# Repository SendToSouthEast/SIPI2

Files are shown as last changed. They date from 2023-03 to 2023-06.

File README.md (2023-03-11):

# SIPI2

一个基于ESP32(IDF)和LVGL实现的多功能单词机

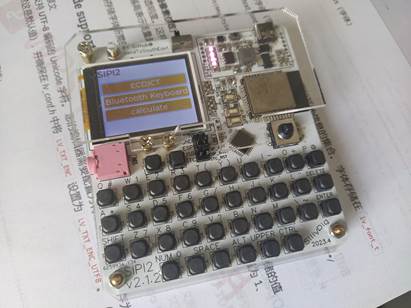
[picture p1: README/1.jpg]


<u>注：以上图片为旧版硬件SIPI2.0</u>

160x128 LCD  SPI屏幕，SPI/SDMMC内存卡存储单词内容，30余个按键全键输入，9x9.5迷你大小，硬件软件全部开源。

作者比较忙，**欢迎各位提交PR，有问题提issue**。git上的issue硬件软件问题都能问，硬件在这里提供json（JLCEDA PCB文件）和gerber。另在立创广场开源硬件项目。

若你只是想复刻这个项目，你可以到release获取所有gerber和二进制文件。

2.0问题已经全部修复，2.1版本还未验证，请知悉！！！

## 项目核心

本项目采用MIT开源，欢迎各位积极贡献代码！！！！

欢迎各位积极贡献代码！！！！

欢迎各位积极贡献代码！！！！

欢迎各位积极贡献代码！！！！

欢迎各位积极贡献代码！！！！

## 功能说明

1.查询单词

2.蓝牙键盘，可以连接手机电脑（进行中）

可开发功能

1.基于LVGL的俄罗斯方块等游戏

2.基于ESP ADF pwm或ADC的音乐播放器

3.基于LVGL的文件浏览器，电子相册

……

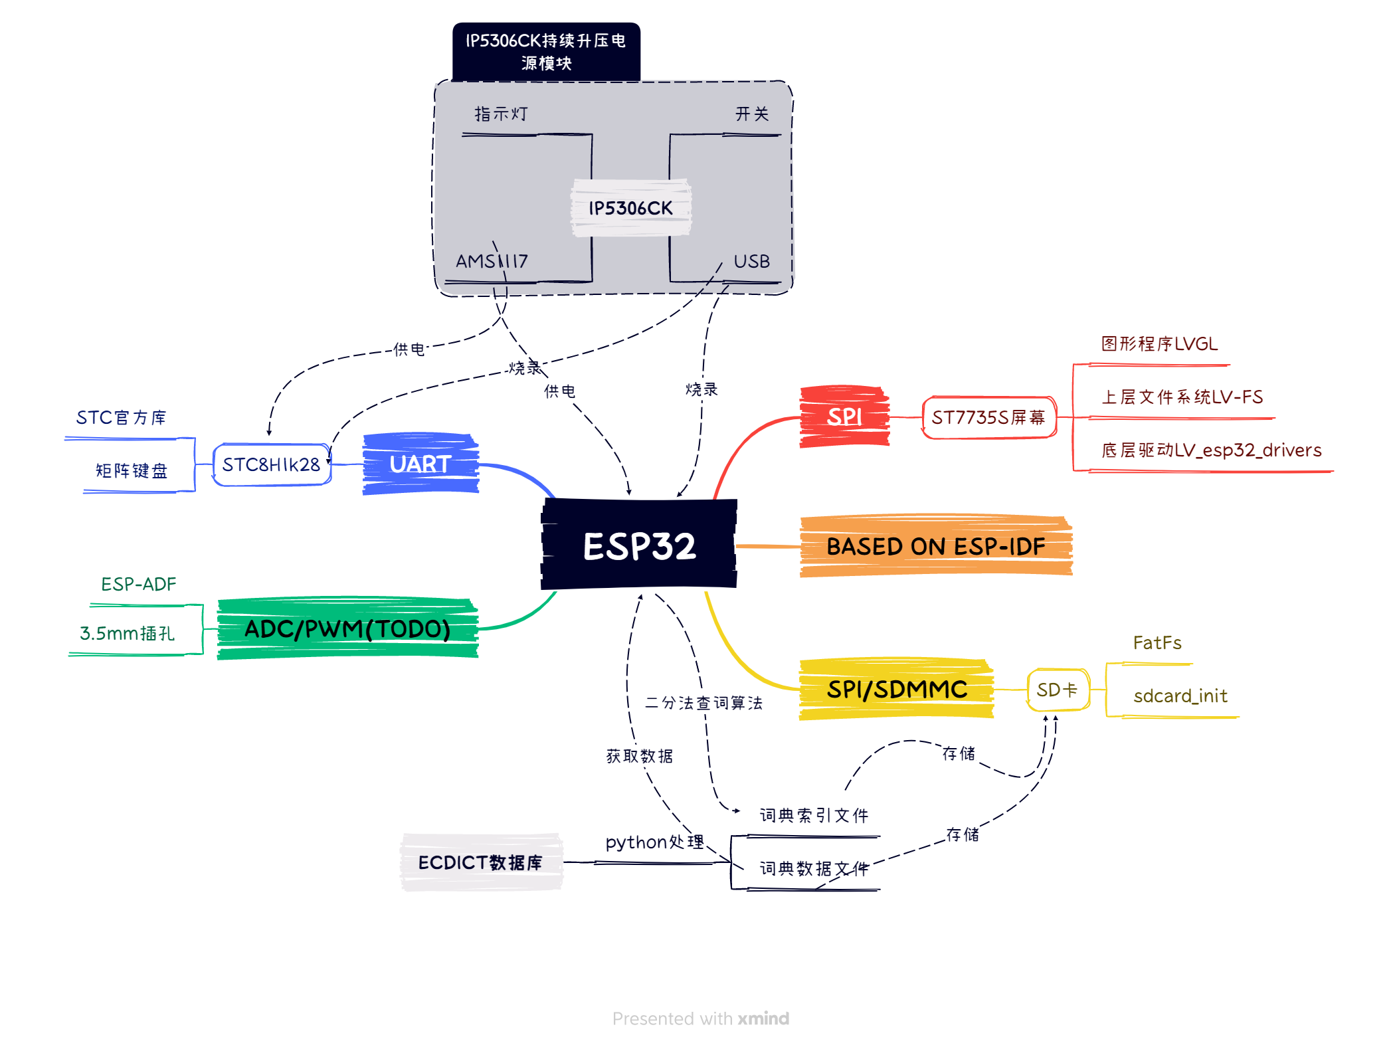
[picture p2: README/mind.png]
mind


## 使用教程

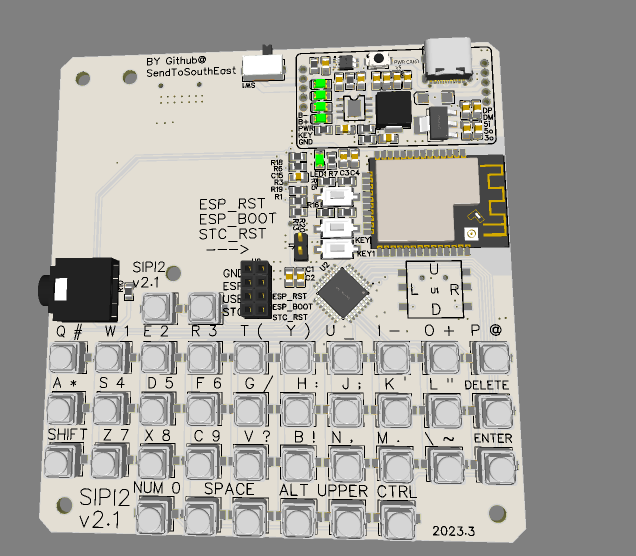
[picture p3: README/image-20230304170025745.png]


以2.1硬件为例。

### 一.烧录

板子上有ESP32的复位按键，BOOT按键和STC8的复位按键。

需要分别给ESP32和STC单片机烧录程序。

若你只是想复刻这个项目，你可以到release获取所有gerber和二进制文件。

[Releases · SendToSouthEast/SIPI2 (github.com)](https://github.com/SendToSouthEast/SIPI2/releases)

#### 1.特制烧录器

本板子不集成串口转换芯片，但是你可以使用某些（自制）非规范的USB线，即DP DM分别是电脑TXD RXD的非规范的USB烧录器连接充电口进行烧录。只需将烧录插座的2.3行(ESP,USB)竖直连起来，就像这样 （A和B代表不同的短接帽）就可以对ESP32进行烧录。

```
OO
AB
AB
OO
```

同理，短接三四行就能对STC烧录。

```
OO
OO
AB
AB
```

#### 2.普通烧录器

这四个位置的定义如下

| GND | GND |
| --- | --- |
| ESP_TXD | ESP_RXD |
| USBDM | USBDP |
| STC_TXD | STC_RXD |

#### 3.注意事项

烧录教程不再写了，网上一查便是，说下注意事项

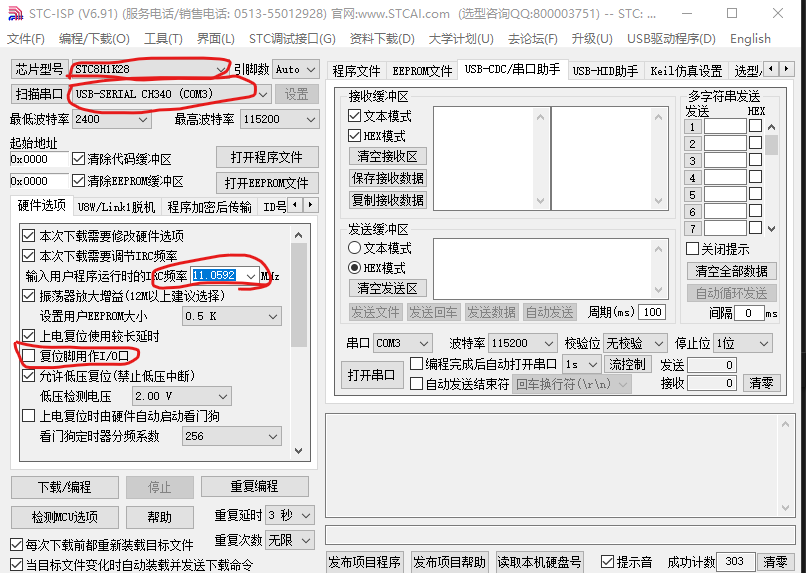
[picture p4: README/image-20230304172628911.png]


图为你烧录STC单片机的注意事项。

当你第一次烧录STC单片机时，复位脚是IO状态，你需要先点击烧录然后再给单片机供电。（具体请查）

当你关闭了复位脚用做IO口，在你**下一次烧录**时，不需要断电，先点击烧录再按下复位即可。

建议每次烧录都关闭复位脚用做IO口。注意，它默认是打开的，而且不会保存状态。

### 二.使用

打开电源后点击充电芯片的按键，开始供电。

键盘上面的左边的两个按键 是确定键，右边是返回键。

在Dict界面点击确定查词，点击返回进入蓝牙键盘模式。

在Word界面都会返回Dict界面。

目前五向按键尚未投入使用。

按下ALT后进入数字、符号输入模式

按下UPPER进入大写输入模式，再次按下即可取消。

目前因为对HID协议的通信不熟悉，导致符号输入有点问题，（HID有很多两个按键共用一个HID码）望大佬赐教。（如何同时按下shift和按键？）

蓝牙模式下可用手机连接，按照提示配置输入后就可以使用了。

讯飞输入法效果如图

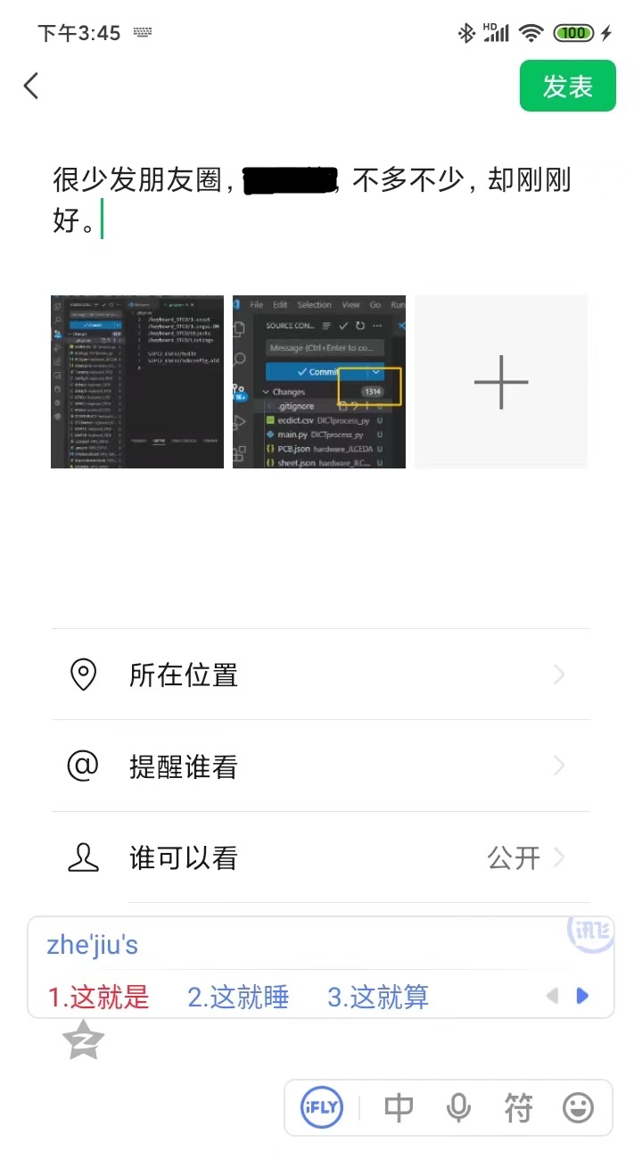
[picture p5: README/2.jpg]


## 硬件说明

**2.0问题已经全部修复，2.1.1版本还未验证，请知悉！！！**

充电部分电路参考[IP5306CK单片机电源板 - 嘉立创EDA开源硬件平台 (oshwhub.com)](https://oshwhub.com/yxynb/IP5306CKPOWERBOARD)

充电模块提供3.3V电源。

STC8单片机扫描键盘并通过串口2发送给ESP32。

### 重要物料BOM

并未有任何推广，你如果能在淘宝或者哪里买到更便宜的当然更好

| 元件 | 说明 | 示例链接 |
| --- | --- | --- |
| XB7608AJ | 锂电池保护芯片 | https://item.szlcsc.com/2775921.html |
| IP5306CK | 充电芯片（持续升压） | [原装正品 IP5306_CK ESOP-8 2.1A充电2.4A放电 移动电源SOC芯片-淘宝网 (taobao.com)](https://item.taobao.com/item.htm?spm=a1z10.3-c-s.w4002-24706531953.12.68fe6a4bBAzjuy&id=663023987923) |
| STC8H1K28-LQFP32 | 键盘扫描芯片 | [STC8H1K28-36I-LQFP32 全新原装 STC8H1K28-淘宝网 (taobao.com)](https://item.taobao.com/item.htm?spm=a230r.1.14.36.57ea73fbUVK0uj&id=615435436806&ns=1&abbucket=16#detail) |
| ESP32-WROOM32 | 主控 | 用兼容新产品也可 |
| 1.77寸TFT液晶显示屏14PIN焊接式ST7735S | 屏幕 | [1.77寸TFT液晶显示屏14PIN焊接SPI接口1.8寸显示屏14PIN串口SPI-淘宝网 (taobao.com)](https://item.taobao.com/item.htm?spm=a230r.1.14.13.41762419pn5ZGc&id=579752045837&ns=1&abbucket=16#detail) |
| 160G轻力度无声硅胶开关 | 建议买40个 | [TS-E013 硅胶按钮6*6*5/4.3贴片无声A6按键硅胶车载汽车SW-PB轻触-淘宝网 (taobao.com)](https://item.taobao.com/item.htm?spm=a1z10.3-c-s.w4002-18164922779.14.3d3c6edb4XQNIZ&id=22248047162) |
| 五向开关 | 目前没有用可以不装，买之前对照一下原理图 | [FT-007贴片10*10*5/7/9多功能多方向连接器五向开关 轻触复位按键-淘宝网 (taobao.com)](https://item.taobao.com/item.htm?spm=a1z0d.6639537/tb.1997196601.4.2b777484jefjoa&id=596429062451) |

### 外观尺寸

外观尺寸为90（w）x95（h），以左下角为坐标原点，五个螺丝孔的坐标分别为（单位mm）

| 5,5 | 5,90  |
| ----- | ----- |
| 85,5  | 15,90 |
| 25,49 | |

## 项目结构

仓库共有四个主文件夹（项目）

| 文件夹 | 说明 | 语言/IDE/平台 |
| --- | --- | --- |
| DICTprocess_py  | 将字典数据库处理为一个索引文件和一个数据文件的脚本 | python |
| hardware_JLCEDA | 硬件文件 | 嘉立创EDA |
| keyboard_STC8 | 键盘扫描程序，向主控串口发送数据 | Keil STC8H1K |
| SIPI2_ESP32 | 主控（ESP32）程序 | Vscode ESPIDF v4.4.2 |

其中字典处理的数据库来自[skywind3000/ECDICT](https://github.com/skywind3000/ECDICT)

keyboard_STC8的库文件为STC官方STC8库文件

```
│  .gitignore    // Git 版本控制忽略文件配置
│  LICENSE       // 代码许可证
│  README.md     // 项目说明文档
│
├─DICTprocess_py 	// Python 字典处理程序
│      ecdict.csv   // 英汉词典数据文件（来源见下）
│      main.py      // 主程序文件
│
├─hardware_JLCEDA 	// JLCEDA 硬件设计文件
│      PCB.json     // PCB 文件
│      sheet.json   // 原理图文件
│
├─keyboard_STC8    // STC8 键盘控制器程序
│  │  1.uvproj     // Keil uVision 项目文件
│  │  config.h     // 配置文件
│  │  delay.c      // 延时库稳健
│  │  delay.h      // 延时库头文件
│  │  GPIO.c       // GPIO 库文件
│  │  GPIO.h       // GPIO 库头文件
│  │  mian.c       // 主程序文件
│  │  STARTUP.A51  // Keil ASM 文件
│  │  STC8xxxx.H   // STC8 头文件
│  │  UART.C       // 串口库文件
│  │  UART.h       // 串口库头文件
│
├─README          // 项目说明文档
│      1.jpg      // 图片文件
│
└─SIPI2_ESP32     // ESP32 控制程序
				  //见下
				  
SIPI2_ESP32目录结构如下

│  .cproject
│  .project
│  CMakeLists.txt
│  dependencies.lock
│  partitions.csv			// 分区表文件
│  sdkconfig				// 记录ESP-IDF SDK配置选项的文件
│  sdkconfig.old
│
├─.vscode
│      c_cpp_properties.json
│      settings.json
│
├─components
│  ├─lvgl					// LittlevGL图形库组件
│  │
│  ├─lvgl_esp32_drivers     // LittlevGL在ESP32上的驱动组件
│  │
│  ├─lv_fs_if				// ESP和LVGL文件系统接口组件
│  │
│  └─sdcard_init			// SD卡初始化驱动程序组件(自编)
│          CMakeLists.txt
│          Kconfig			// 配置选项文件
│          sdcard_init.c	// SD卡初始化驱动程序的源代码文件
│          sdcard_init.h
│
└─main
	│  character.txt				// 存储字库字符的文本文件
	│  CMakeLists.txt
	│  config.h						// 配置选项头文件
	│  donotuse.txt
	│  init.c						// 初始化
	│  init.h
	│  Kconfig.projbuild
	│  main.c						// 主程序
	│  main.h
	│  simhei.c						// 简体中文黑体字体
	│
	├─scenes                        // 场景代码
	│  dictScene.c                  // 字典场景的源文件
	│  HIDScene.c                   // HID场景的源文件
	│  scenes.h                     // 场景代码的头文件
	│  wordScene.c                  // 单词场景的源文件
	│
	└─srcs							// 功能代码
    	├─blueHID					// 蓝牙HID功能代码
    	│      ble_hidd.c
 	   	│      ble_hidd.h
 	   	│      esp_hidd_prf_api.c
 	   	│      esp_hidd_prf_api.h
 	   	│      hidd_le_prf_int.h
  	  	│      hid_dev.c
  	  	│      hid_dev.h
	  	│      hid_device_le_prf.c
	    │
    	└─englishDict              // 英语词典代码
        englishDict.c              // 英语词典查词算法
        englishDict.h
```

其中，lvgl_esp32_drivers的st7735的屏幕驱动程序有修改，为兼容此屏幕。

sdcard_init是我写的component，引脚配置和模式选择在menuconfig中。之所以做成组件是因为lv_fs_if需要调用它来初始化文件系统。

本项目由去年写的代码第二次重构（第一次重构由arduino转到IDF，第二次模块化去耦），一些函数的实现没有动，若不规范欢迎大家指出改正！

## TODO

1.蓝牙键盘有点问题，目前因为对HID协议的通信不熟悉，导致符号输入有点问题，（HID有很多两个按键共用一个HID码）望大佬赐教。（如何同时按下shift和按键？

（SIPI2_ESP32\main\srcs\blueHID\ble_hidd.c）不能正确运行。

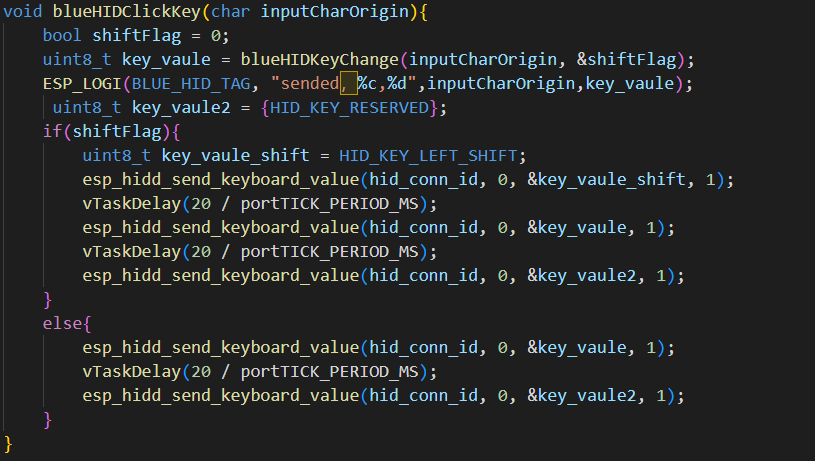
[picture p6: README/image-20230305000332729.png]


2.将五向开关利用起来

3.可能会做单词语音播放（还未开工）

4.你想做什么功能欢迎提交称为贡献者

## 开源许可

本项目采用MIT开源协议。同时也希望其它esp32项目多开源。

但是，请勿将我的项目搬运上传码云等平台。

## 鸣谢

[skywind3000/ECDICT: Free English to Chinese Dictionary Database (github.com)](https://github.com/skywind3000/ECDICT)

[lvgl/lvgl: Embedded graphics library to create beautiful UIs for any MCU, MPU and display type. It's boosted by a professional yet affordable drag and drop UI editor, called SquareLine Studio. (github.com)](https://github.com/lvgl/lvgl)

[lvgl/lvgl_esp32_drivers: Drivers for ESP32 to be used with LVGL (github.com)](https://github.com/lvgl/lvgl_esp32_drivers)

[lvgl/lv_fs_if: LVGL interfaces to various file systems (PC, FatFS) (github.com)](https://github.com/lvgl/lv_fs_if)

[espressif/esp-idf: Espressif IoT Development Framework. Official development framework for Espressif SoCs. (github.com)](https://github.com/espressif/esp-idf)

[FreeRTOS/FreeRTOS: 'Classic' FreeRTOS distribution. Started as Git clone of FreeRTOS SourceForge SVN repo. Submodules the kernel. (github.com)](https://github.com/FreeRTOS/FreeRTOS)

fatfs

感谢[ahzvenol (灵弦) (github.com)](https://github.com/ahzvenol) 的帮助

## 赞助作者

想喝一杯奶茶……可以吗

……家境贫寒……无电子词典可买……徒手搓之……





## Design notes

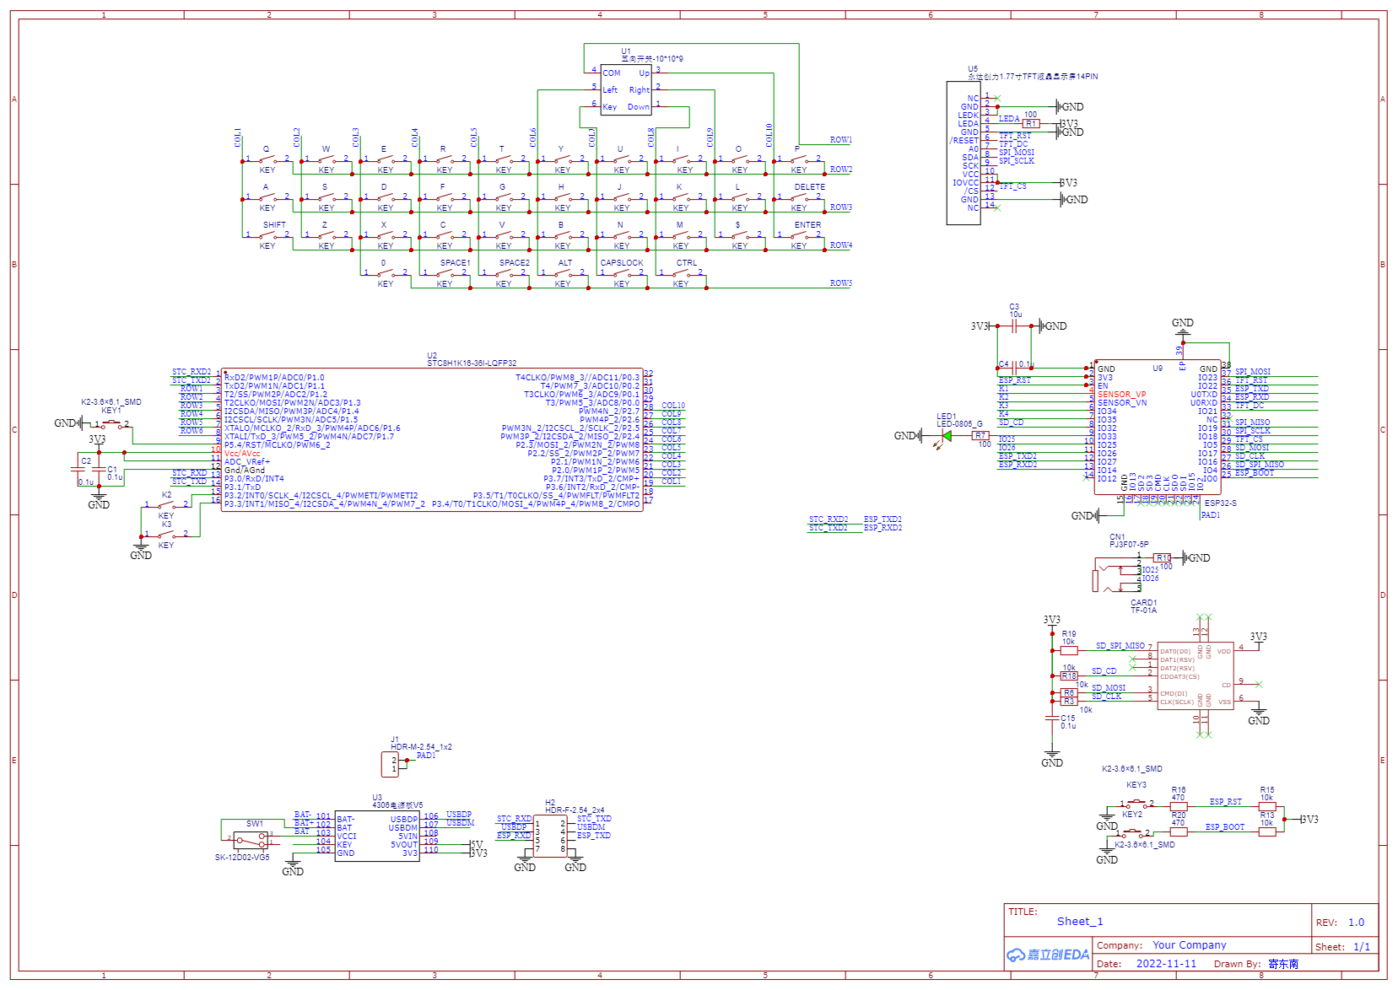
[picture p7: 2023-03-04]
hardware_JLCEDA/Schematic1.png

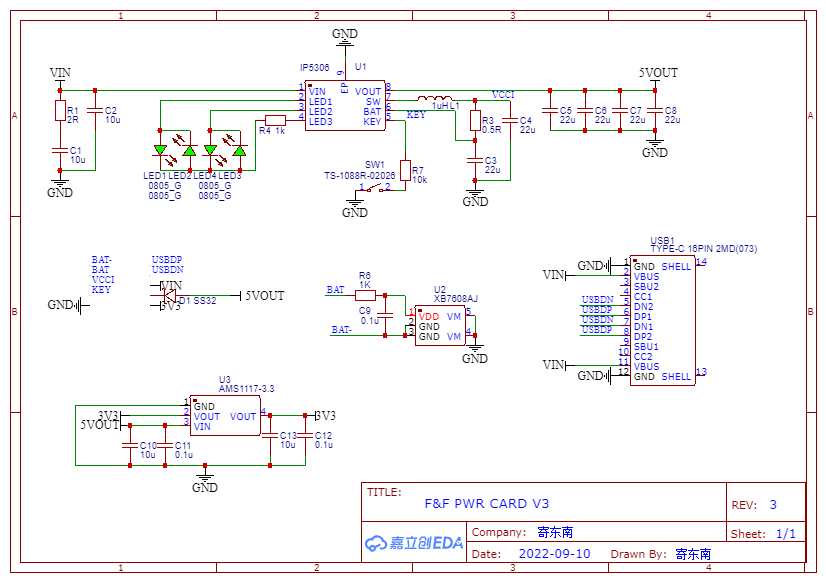
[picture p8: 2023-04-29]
hardware_JLCEDA/Schematic2.png

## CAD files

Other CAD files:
hardware_JLCEDA/亚克力双面板外壳.dwg

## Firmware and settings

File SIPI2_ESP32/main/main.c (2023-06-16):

#include "main.h"


#include "simhei.c"
#include "scenes.h"

static const char *TAG = "SIPI2_MAIN";

void keyCheakTask();

uint8_t LVKeyYBuff = 0;

bool keyYesFlag = 0;
bool keyNOFlag = 0;
bool inputFlag = 0;
char InputBuffer = 0;



// 初始化UI
void UIInit()
{
    //oald10WordSceneInit("add to");
    //oald10DictSceneInit();
    lv_obj_set_size(lv_obj_create(NULL), LV_HOR_RES, LV_VER_RES);
    mainSceneInit();
}


lv_obj_t* scr;
lv_obj_t* scr1;

void win_test1(void)
 {
     scr = lv_obj_create(NULL);
     lv_obj_set_size(scr, LV_HOR_RES, LV_VER_RES);
     static lv_style_t style;
     lv_style_reset(&style);
     lv_style_init(&style);
     lv_style_set_bg_color(&style, lv_palette_main(LV_PALETTE_RED));
     lv_style_set_text_color(&style, lv_color_white());
     lv_obj_add_style(scr, &style,NULL);

     lv_obj_t* label = lv_label_create(scr);
     lv_obj_set_style_text_color(label, lv_color_hex(0x990000), LV_PART_MAIN | LV_STATE_DEFAULT);
    

     lv_label_set_text(label, "This is a test 1");

     lv_scr_load_anim(scr, LV_SCR_LOAD_ANIM_FADE_ON, 400, 0, true);
     printf("win test 1 is created ");
 }

 void win_test2(void)
 {
     scr1 = lv_obj_create(NULL);
     lv_obj_set_size(scr1, LV_HOR_RES, LV_VER_RES);
     static lv_style_t style;
     lv_style_reset(&style);
     lv_style_init(&style);
     lv_style_set_bg_color(&style, lv_palette_main(LV_PALETTE_BLUE));
     lv_style_set_text_color(&style, lv_color_white());
     
     lv_obj_add_style(scr1, &style,NULL);

     lv_obj_t* label = lv_label_create(scr1);
     lv_obj_set_style_text_color(label, lv_color_hex(0x990000), LV_PART_MAIN | LV_STATE_DEFAULT);

     lv_label_set_text(label, "This is a test 2");
     
     lv_scr_load_anim(scr1, LV_SCR_LOAD_ANIM_FADE_ON, 0, 0,true);
     printf("win test 2 is created ");
 }


void lv_tick_task(void *arg)
{
    lv_tick_inc(1);
}

// LVGL初始化和任务
void guiTask(void *p){
    SIPI_LOGI(TAG, "Initializing LVGL");
    lv_init();
    lvgl_driver_init();
    lv_color_t *buf1 = heap_caps_malloc(DISP_BUF_SIZE * sizeof(lv_color_t), MALLOC_CAP_DMA);
    assert(buf1 != NULL);
    static lv_color_t *buf2 = NULL;

    static lv_disp_draw_buf_t disp_buf;

    uint32_t size_in_px = DISP_BUF_SIZE;
    lv_disp_draw_buf_init(&disp_buf, buf1, buf2, size_in_px);
    static lv_disp_drv_t disp_drv;
    lv_disp_drv_init(&disp_drv);
    disp_drv.hor_res = LV_HOR_RES_MAX; //横向分辨率
    disp_drv.ver_res = LV_VER_RES_MAX; //纵向分辨率
    disp_drv.flush_cb = disp_driver_flush; //设置显示刷新函数
    disp_drv.draw_buf = &disp_buf;
    disp_drv.sw_rotate = 0; //逆时针旋转角度（90，180，270）
    lv_disp_drv_register(&disp_drv); //向LVGL注册驱动

    const esp_timer_create_args_t periodic_timer_args = {
        .callback = &lv_tick_task,
        .name = "periodic_gui"};
    esp_timer_handle_t periodic_timer;
    ESP_ERROR_CHECK(esp_timer_create(&periodic_timer_args, &periodic_timer));
    ESP_ERROR_CHECK(esp_timer_start_periodic(periodic_timer, 1 * 1000));

    lv_disp_set_rotation(NULL, LV_DISP_ROT_180);

    lv_indev_drv_t indev_drv;
    lv_indev_drv_init(&indev_drv);      /*Basic initialization*/
    indev_drv.type = LV_INDEV_TYPE_KEYPAD;                 /*See below.*/
    indev_drv.read_cb = key_read;            /*See below.*/
    /*Register the driver in LVGL and save the created input device object*/
    indev_keypad = lv_indev_drv_register(&indev_drv);

    LV_FONT_DECLARE(simhei);//声明字体simhei

    lv_fs_if_init();

    SIPI_LOGI(TAG, "Initialized LVGL");
    UIInit();
    while (1)
    {
        /* Delay 1 tick (assumes FreeRTOS tick is 10ms */
        vTaskDelay(pdMS_TO_TICKS(10));
        keyCheakTask();
        lv_task_handler();

        // static uint16_t i;
        // if (++i > 100) {
        //     i = 0;
        //     static bool flag;
        //     if (flag)
        //     {
        //         flag = false;
        //         win_test2();
        //     }
        //     else
        //     {
        //         flag = true;
        //         win_test1();
        //     }
        // }

    }

}
void keyCheakTask(){
    if(keyYesFlag == 1){
        keyYesFlag = 0;
        switch (scene){
        case SIPI_SCENE_dictScene:
            dictSceneYESEvent();
            break; 
        case SIPI_SCENE_wordScene:
            wordSceneYESEvent();
            break;
        case SIPI_SCENE_calcScene:
            calcSceneYESEvent();
            break;
        case SIPI_SCENE_oald10DictScene:
            oald10DictSceneYESEvent();
            break;
        case SIPI_SCENE_oald10WordScene:
            oald10WordSceneYESEvent();
            break;
        default:
                break;
        }
    }
    if(keyNOFlag == 1){
        keyNOFlag = 0;
        switch (scene){
        case SIPI_SCENE_dictScene:
            dictSceneNOEvent();
            break; 
        case SIPI_SCENE_wordScene:
            wordSceneNOEvent();
            break;
        case SIPI_SCENE_calcScene:
            calcSceneNOEvent();
            break;
        case SIPI_SCENE_oald10DictScene:
            oald10DictSceneNOEvent();
            break;
        case SIPI_SCENE_oald10WordScene:
            oald10WordSceneNOEvent();
            break;
        default:
                break;
        }
    }
    if(inputFlag != 0){
        inputFlag = 0;
        switch (scene){
        case SIPI_SCENE_dictScene:
            dictSceneInputEvent(InputBuffer);
            break;    
        case SIPI_SCENE_HIDScene:
            HIDSceneInputEvent(InputBuffer);
            break;  
        case SIPI_SCENE_calcScene:
            calcSceneInputEvent(InputBuffer);
            break;  
        case SIPI_SCENE_oald10DictScene:
            oald10DictSceneInputEvent(InputBuffer);
            break; 
        default:
                break;
        }
    }

}
void keyBoardReadTask(void *p)
{
    while(1)
    {
        //串口键盘
        vTaskDelay(pdMS_TO_TICKS(10));
        char uartCharBuf = cheakUartKeyboard();
        if(uartCharBuf){
            bool addChar = SIPI_YES;
            bool LVKeys = SIPI_NO;
            char inputCharOrigin = uartCharBuf;
            //SIPI_LOGI(TAG, "%c",inputCharOrigin);

            //0x01 NONE
            //0x02 NUM  -
            //0x03 ALT  -
            //0x04 UPPER -
            //0x05 CTRL
            //0x06 SHIFT
            //0x07 ENTER
            //0x08 DELETE
            //0x09 YES
            //0x10 No
            switch (inputCharOrigin){
                case 0x09:addChar = SIPI_NO;keyYesFlag = 1;break;
                case 0x10:addChar = SIPI_NO;keyNOFlag = 1;break;
                case 0x07:inputCharOrigin='\n';break;//enter
                case 0x08:inputCharOrigin= 0x00;break;//delete



                case 0x0A:addChar = SIPI_NO;LVKeys = SIPI_YES;LVKeyYBuff = LV_KEY_LEFT;break;
                case 0x0B:addChar = SIPI_NO;LVKeys = SIPI_YES;LVKeyYBuff = LV_KEY_ENTER;break;
                case 0x0C:addChar = SIPI_NO;LVKeys = SIPI_YES;LVKeyYBuff = LV_KEY_DOWN;break;
                case 0x0D:addChar = SIPI_NO;LVKeys = SIPI_YES;LVKeyYBuff = LV_KEY_RIGHT;break;
                case 0x0E:addChar = SIPI_NO;LVKeys = SIPI_YES;LVKeyYBuff = LV_KEY_UP;break;
            }


            if(addChar){
                //SIPI_LOGI(TAG, "addChar%c",inputCharOrigin);
                InputBuffer = inputCharOrigin;
                inputFlag = 1;
            }
        }
        vTaskDelay(10 / portTICK_RATE_MS );
    }

}

uint8_t cheakLVKey(){
    if(LVKeyYBuff){
        uint8_t LVKeyYBuff_ = LVKeyYBuff;
        LVKeyYBuff = 0;
        return LVKeyYBuff_;
    }
    else{
        return 0;
    }
}


void app_main(void)
{
    UART2_INIT();
    //GPIO_INIT();
    xTaskCreate(guiTask,"gui",1024*32,NULL,1,NULL);
    xTaskCreate(keyBoardReadTask,"keyboard",1024*2,NULL,1,NULL);

}

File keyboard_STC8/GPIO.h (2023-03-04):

/*---------------------------------------------------------------------*/
/* --- STC MCU Limited ------------------------------------------------*/
/* --- STC 1T Series MCU Demo Programme -------------------------------*/
/* --- Mobile: (86)13922805190 ----------------------------------------*/
/* --- Fax: 86-0513-55012956,55012947,55012969 ------------------------*/
/* --- Tel: 86-0513-55012928,55012929,55012966 ------------------------*/
/* --- Web: www.STCMCU.com --------------------------------------------*/
/* --- Web: www.STCMCUDATA.com  ---------------------------------------*/
/* --- QQ:  800003751 -------------------------------------------------*/
/* 如果要在程序中使用此代码,请在程序中注明使用了STC的资料及程序            */
/*---------------------------------------------------------------------*/

#ifndef	__GPIO_H
#define	__GPIO_H

#include	"config.h"

#define	GPIO_PullUp		0	//上拉准双向口
#define	GPIO_HighZ		1	//浮空输入
#define	GPIO_OUT_OD		2	//开漏输出
#define	GPIO_OUT_PP		3	//推挽输出

#define	GPIO_Pin_0		0x01	//IO引脚 Px.0
#define	GPIO_Pin_1		0x02	//IO引脚 Px.1
#define	GPIO_Pin_2		0x04	//IO引脚 Px.2
#define	GPIO_Pin_3		0x08	//IO引脚 Px.3
#define	GPIO_Pin_4		0x10	//IO引脚 Px.4
#define	GPIO_Pin_5		0x20	//IO引脚 Px.5
#define	GPIO_Pin_6		0x40	//IO引脚 Px.6
#define	GPIO_Pin_7		0x80	//IO引脚 Px.7
#define	GPIO_Pin_All	0xFF	//IO所有引脚
	
#define	GPIO_P0			0		//
#define	GPIO_P1			1
#define	GPIO_P2			2
#define	GPIO_P3			3
#define	GPIO_P4			4
#define	GPIO_P5			5
#define	GPIO_P6			6
#define	GPIO_P7			7


typedef struct
{
	u8	Mode;		//IO模式,  		GPIO_PullUp,GPIO_HighZ,GPIO_OUT_OD,GPIO_OUT_PP
	u8	Pin;		//要设置的端口	
} GPIO_InitTypeDef;

u8	GPIO_Inilize(u8 GPIO, GPIO_InitTypeDef *GPIOx);

#endif

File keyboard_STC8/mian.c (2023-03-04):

#include "config.h"
#include "delay.h"
#include "GPIO.h"
#include "UART.h"
#define uchar unsigned char
#define uint unsigned int
	
#define FOSC 11059200UL
#define BRT (65536 - FOSC / 115200 / 4)
#define NULL '1'

#define I2C_S0	0x10
#define I2C_S1	0x20
#define EAXFR	0x80

sbit SDA = P1^4;
sbit SCL = P1^5;

sbit Row1 = P1^6;
sbit Row2 = P1^5;
sbit Row3 = P1^4;
sbit Row4 = P1^3;
sbit Row5 = P1^2;


sbit COL1 = P3^6;
sbit COL2 = P3^7;
sbit COL3 = P2^0;
sbit COL4 = P2^1;
sbit COL5 = P2^2;
sbit COL6 = P2^3;
sbit COL7 = P2^4;
sbit COL8 = P2^5;
sbit COL9 = P2^6;
sbit COL10 = P2^7;

sbit Key1 = P3^3;
sbit Key2 = P3^2;

//0x01 NONE
//0x02 NUM
//0x03 ALT
//0x04 UPPER
//0x05 CTRL
//0x06 SHIFT
//0x07 ENTER
//0x08 DELETE
//0x09 YES
//0x10 No
code char keyboard[10][5] = {
{0x01,0x06,'a','q',0x01},
{0x01,'z','s','w',0x01},
{'0','x','d','e',0x01},
{' ','c','f','r',0x01},
{' ','v','g','t',0x01},
{0x03,'b','h','y',0x01},
{0x04,'n','j','u',0x01},
{0x05,'m','k','i',0x01},
{0x01,'\\','l','o',0x01},
{0x01,0x07,0x08,'p',0x01}
};
code char keyboardup[10][5] = {
{0X01,0X06,'A','Q',0X01},
{0X01,'Z','S','W',0X01},
{'0','X','D','E',0X01},
{' ','C','F','R',0X01},
{' ','V','G','T',0X01},
{0X03,'B','H','Y',0X01},
{0X04,'N','J','U',0X01},
{0X05,'M','K','I',0X01},
{0X01,'\\','L','O',0X01},
{0X01,0X07,0X08,'P',0X01}
};
code char keyboardnum[10][5] = {
{0x01,0x06,'*','#',0x01},
{0x01,'7','4','1',0x01},
{'0','8','5','2',0x01},
{' ','9','6','3',0x01},
{' ','?','/','(',0x01},
{0x03,'!',':',')',0x01},
{0x04,',',';','_',0x01},
{0x05,'.','\'','-',0x01},
{0x01,'~','\"','+',0x01},
{0x01,0x07,0x08,'@',0x01}
};

bit upMode = 0;
bit numMode = 0;

char lastkey = 0x00;
char lastkeydown;
bit busy;
char wptr;
char rptr;
char buffer[16];



void UartSend(char dat);
void GPIOInit(){
	P0M0 = 0x00;
	P0M1 = 0x00;
	P1M0 = 0x00;
	P1M1 = 0x00;
	P2M0 = 0x00;
	P2M1 = 0x00;
	P3M0 = 0x00;
	P3M1 = 0x00;
	P5M0 = 0x00;
	P5M1 = 0x00;
	
	Key1 = 1;
	Key2 = 1;
}
void ROWUpDown(bit a){
	Row1 = a;
	Row2 = a;
	Row3 = a;
	Row4 = a;
	Row5 = a;

}
void COLUpDown(bit a){
	COL1 = a;
	COL2 = a;
	COL3 = a;
	COL4 = a;
	COL5 = a;
	COL6 = a;
	COL7 = a;
	COL8 = a;
	COL9 = a;
	COL10 = a;
}
void KeyInit(){
	ROWUpDown(1);
	COLUpDown(0);
}
bit ifROWDown(){
	if(!(Row1&Row2&Row3&Row4&Row5)){
		delay_ms(10);
		if(!(Row1&Row2&Row3&Row4&Row5)){//(!(Row1&Row2&Row3&Row4&Row5&Row6&Row7)){
		return 1;
		}
	}
	else{
		return 0;
	}
}
void keyboardinit();
char KeyScan(){
	uchar Line1 = 0;
	uchar Line2 = 0;
	uchar Line3 = 0;
	uchar Line4 = 0;
	uchar P1old = 0x00;
	uchar originKey = 0x00;
	uchar finallyKey = 0x00;
	KeyInit();
	
	delay_ms(1);
	if(Key1 == 0){
		delay_ms(10);
		if(Key1 == 0){
			return 0x09;
		}
	}
	
	if(Key2 == 0){
		delay_ms(10);
		if(Key2 == 0){
			return 0x10;
		}
	}
	
	if(ifROWDown()){
		uchar i = 1;	
		if(!Row1){if(Line1 > 0){Line3 = 1;}else{Line1 = 1;}}
		if(!Row2){if(Line1 > 0){Line3 = 2;}else{Line1 = 2;}}
		if(!Row3){if(Line1 > 0){Line3 = 3;}else{Line1 = 3;}}
		if(!Row4){if(Line1 > 0){Line3 = 4;}else{Line1 = 4;}}
		if(!Row5){if(Line1 > 0){Line3 = 5;}else{Line1 = 5;}}
		
		P1old = P1;
		//P1 = 0x30 & P1old;
		for(i = 1;i < 11;i++){
			COLUpDown(1);
			if(i == 1)COL1 = 0;
			if(i == 2)COL2 = 0;
			if(i == 3)COL3 = 0;
			if(i == 4)COL4 = 0;
			if(i == 5)COL5 = 0;
			if(i == 6)COL6 = 0;
			if(i == 7)COL7 = 0;
			if(i == 8)COL8 = 0;
			if(i == 9)COL9 = 0;
			if(i == 10)COL10 = 0;
			delay_ms(1);
			if(Line1 == 1){if(!Row1){if(!Line2)Line2 = i;}}
			if(Line1 == 2){if(!Row2){if(!Line2)Line2 = i;}}
			if(Line1 == 3){if(!Row3){if(!Line2)Line2 = i;}}
			if(Line1 == 4){if(!Row4){if(!Line2)Line2 = i;}}
			if(Line1 == 5){if(!Row5){if(!Line2)Line2 = i;}}
		}
		COLUpDown(0);
		while(!(Row1&Row2&Row3&Row4&Row5));
		delay_ms(10);
		while(!(Row1&Row2&Row3&Row4&Row5));
		originKey = keyboard[Line2-1][Line1-1];
		if(originKey == 0x04){
			upMode = !upMode;
			return 0x00;
		}
		if(originKey == 0x03){
			numMode = !numMode;
			return 0x00;
		}
		else if(upMode == 1){
			finallyKey = keyboardup[Line2-1][Line1-1];
			return finallyKey;
		}
		else if(numMode == 1){
			finallyKey = keyboardnum[Line2-1][Line1-1];
			return finallyKey;
		}
		else{
			return keyboard[Line2-1][Line1-1];
		}
	}
	else{
		return 0x00;
	}
}




#ifdef USEUART2
void	GPIO_config(void)
{
	GPIO_InitTypeDef	GPIO_InitStructure;		//结构定义

	GPIO_InitStructure.Pin  = GPIO_Pin_6 | GPIO_Pin_7;		//指定要初始化的IO, GPIO_Pin_0 ~ GPIO_Pin_7
	GPIO_InitStructure.Mode = GPIO_PullUp;	//指定IO的输入或输出方式,GPIO_PullUp,GPIO_HighZ,GPIO_OUT_OD,GPIO_OUT_PP
	GPIO_Inilize(GPIO_P4,&GPIO_InitStructure);	//初始化
}

/***************  串口初始化函数 *****************/
void	UART_config(void)
{
	COMx_InitDefine		COMx_InitStructure;					//结构定义
	COMx_InitStructure.UART_Mode      = UART_8bit_BRTx;		//模式,   UART_ShiftRight,UART_8bit_BRTx,UART_9bit,UART_9bit_BRTx
//	COMx_InitStructure.UART_BRT_Use   = BRT_Timer2;			//选择波特率发生器, BRT_Timer2 (注意: 串口2固定使用BRT_Timer2, 所以不用选择)
	COMx_InitStructure.UART_BaudRate  = 115200ul;			//波特率,     110 ~ 115200
	COMx_InitStructure.UART_RxEnable  = ENABLE;				//接收允许,   ENABLE或DISABLE
	COMx_InitStructure.UART_Interrupt = ENABLE;				//中断允许,   ENABLE或DISABLE
	COMx_InitStructure.UART_Priority    = Priority_0;			//指定中断优先级(低到高) Priority_0,Priority_1,Priority_2,Priority_3
	COMx_InitStructure.UART_P_SW      = UART2_SW_P10_P11;	//切换端口,   UART2_SW_P10_P11,UART2_SW_P46_P47
	UART_Configuration(UART2, &COMx_InitStructure);		//初始化串口2 UART1,UART2,UART3,UART4
}
#endif
#ifdef USEUART1
void	GPIO_config(void)
{
	GPIO_InitTypeDef	GPIO_InitStructure;		//结构定义

	GPIO_InitStructure.Pin  = GPIO_Pin_0 | GPIO_Pin_1;		//指定要初始化的IO, GPIO_Pin_0 ~ GPIO_Pin_7
	GPIO_InitStructure.Mode = GPIO_PullUp;	//指定IO的输入或输出方式,GPIO_PullUp,GPIO_HighZ,GPIO_OUT_OD,GPIO_OUT_PP
	GPIO_Inilize(GPIO_P3,&GPIO_InitStructure);	//初始化
}

/***************  串口初始化函数 *****************/
void	UART_config(void)
{
	COMx_InitDefine		COMx_InitStructure;					//结构定义
	COMx_InitStructure.UART_Mode      = UART_8bit_BRTx;	//模式, UART_ShiftRight,UART_8bit_BRTx,UART_9bit,UART_9bit_BRTx
	COMx_InitStructure.UART_BRT_Use   = BRT_Timer1;			//选择波特率发生器, BRT_Timer1, BRT_Timer2 (注意: 串口2固定使用BRT_Timer2)
	COMx_InitStructure.UART_BaudRate  = 115200ul;			//波特率, 一般 110 ~ 115200
	COMx_InitStructure.UART_RxEnable  = ENABLE;				//接收允许,   ENABLE或DISABLE
	COMx_InitStructure.BaudRateDouble = DISABLE;			//波特率加倍, ENABLE或DISABLE
	COMx_InitStructure.UART_Interrupt = ENABLE;				//中断允许,   ENABLE或DISABLE
	COMx_InitStructure.UART_Priority    = Priority_0;			//指定中断优先级(低到高) Priority_0,Priority_1,Priority_2,Priority_3
	COMx_InitStructure.UART_P_SW      = UART1_SW_P30_P31;	//切换端口,   UART1_SW_P30_P31,UART1_SW_P36_P37,UART1_SW_P16_P17,UART1_SW_P43_P44
	UART_Configuration(UART1, &COMx_InitStructure);		//初始化串口1 UART1,UART2,UART3,UART4
}
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

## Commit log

2023-03-04 first test
    [partitions.csv]
2023-03-26 Fixed bug with displaying phonetic symbol theta (θ).
2023-04-04 Added shell dxf file and moved screw hole position
    [亚克力双面板外壳.dwg]
2023-04-14 add support for esp32-solo
2023-04-14 update ver tag on PCB
2023-04-15 Add five-way switch drive
2023-04-29 fix: Replace incorrect schematic with updated ver
2023-04-30 feat: Add SIPI_LOGE error logging function
    [init.c, init.h]
2023-04-30 fix: Remove extra newline in label text, filter for ASCII code 13
2023-05-08 fix: free memory completely for certain scenes
    [main.c]
